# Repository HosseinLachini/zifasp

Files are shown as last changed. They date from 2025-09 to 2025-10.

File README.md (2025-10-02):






# SANA USBasp – Smart ZIF-Socket AVR Programmer

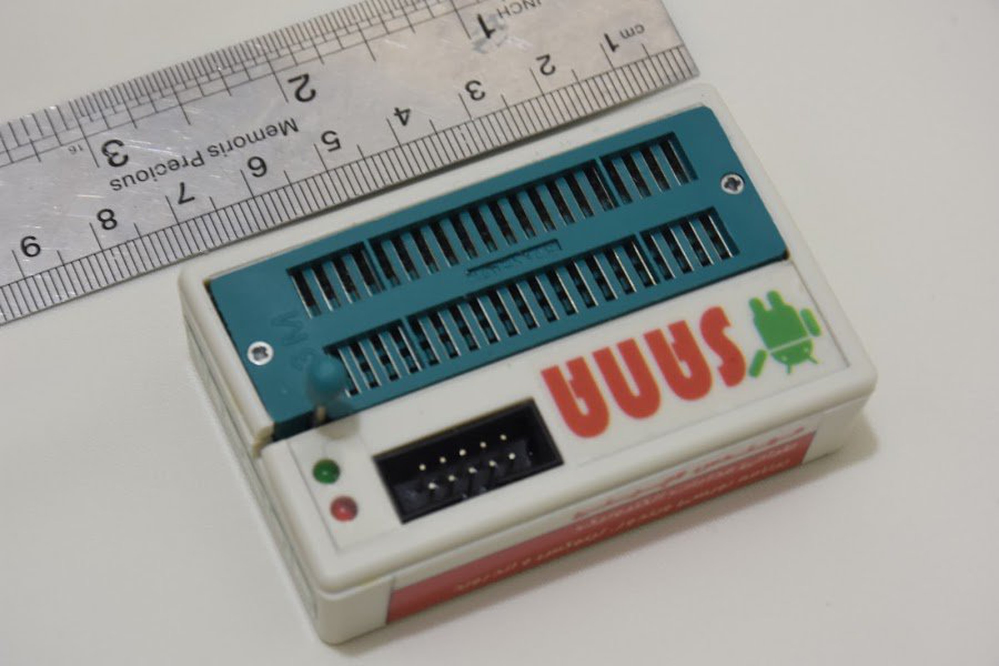
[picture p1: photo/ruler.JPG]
Pocket size — next to a ruler


A compact, USB-powered AVR programmer with an integrated **40-pin ZIF socket** and **auto-wiring** logic. It speaks the standard **USBasp** protocol, so it works out-of-the-box with `avrdude` on **Linux / Windows / macOS** — and even **Android** (OTG) via ZFlasher AVR.

> **Credit & Origin**  
> This project is **based on the original USBasp** by **Thomas Fischl** (the excellent reference design and idea). See: https://www.fischl.de/usbasp/  
> SANA USBasp extends that design with a smart ZIF socket, auto-detect wiring, on-board clock injection, status LEDs, **I²C/SPI EEPROM programming**, and more (details below).

---

## Highlights

- **Smart 40-pin ZIF socket** with **auto-detect package & wiring**  
  Drop any **DIP 8/14/20/28/40** AVR **starting at pin-1** in the ZIF — the programmer **detects the device position automatically** and routes all signals you need:
  `VCC`, `GND`, `RESET`, `SCK`, `MOSI`, `MISO`, and even an **external clock** to the MCU’s `XTAL1` pin when needed.  
  No jumpers, no DIP-switches, no relocating the chip for different packages.

- **Fuse-proof clock injection**  
  If fuses were set for an external clock/oscillator (and your chip “bricked” due to a disabled internal RC), SANA will **supply the clock** so you can program it again.

- **IDC-10 ISP header with clock out**  
  The 10-pin IDC connector also provides a **clock output** for in-circuit programming (**ISP**) on boards where the target oscillator isn’t running.

- **Driver-state indicator (Windows)**  
  Red LED stays on when the driver isn’t installed; once the USBasp driver is correctly installed, the **green LED** indicates proper enumeration.

- **I²C/SPI EEPROM programmer**  
  Supports popular serial EEPROM families: **24Cxxx** (I²C) and **93Cxx** (Microwire/SPI-like). You can read/write/verify these EEPROMs directly in the ZIF socket.  
  On **Windows**, the **ProgISP** utility provides a convenient GUI for these memories.

- **Pocket-size** — basically the footprint of a 40-pin ZIF; truly **grab-and-go**.

- **USB-powered** (5 V from the host).

- **Fully USBasp-compatible**  
  Works with `avrdude` and common GUI front-ends across Linux/Windows/macOS — plus **Android** via **ZFlasher AVR**.

- **Field-proven**  
  Used by customers in the **USA**, **Italy**, and **Netherlands**.

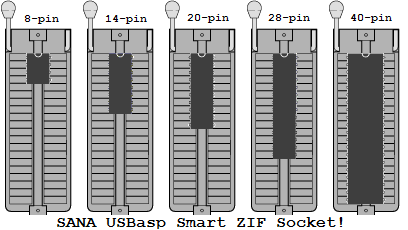
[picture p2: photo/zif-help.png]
ZIF placement guide — always start at pin-1


### IDC-10 ISP Header Pinout (SANA)

When programming targets in-circuit, use the **10-pin IDC** header. It also carries the **rescue clock** (`PROG_XTL1`) to keep “fuse-bricked” MCUs alive during programming.

> ⚠️ **Cautions**  
> • If your target board is self-powered, **do not connect PROG_VCC** (Pin 4).  
> • Always verify **keying/orientation** (Pin-1) before plugging the cable.  
> • For EEPROMs, ensure the device capacity matches the operation and that any **WP** (write-protect) pins are not asserted.  
> • If your target isn’t 5 V tolerant, use proper **level shifting** and power arrangements.

| Pin | Signal | Notes |
|:---:|---|---|
| 1 | PROG_SCK | SPI clock |
| 2 | PROG_GND | Ground |
| 3 | PROG_MISO | MCU → Programmer |
| 4 | PROG_VCC | **Optional** target power (disconnect if self-powered) |
| 5 | PROG_XTL1 | **Clock injection** to target `XTAL1` |
| 6 | PROG_RESET  | Target reset |
| 7 | — | Not connected |
| 8 | — | Not connected |
| 9 | PROG_MOSI | Programmer → MCU |
| 10  | PROG_GND | Ground |

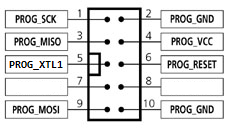
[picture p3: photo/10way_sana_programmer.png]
IDC-10 pinout — SANA programmer


---

## Repository Contents

- Firmware (ATmega88, V-USB/`usbdrv` based)
- Makefile with a friendly `help` target and robust tooling
- Source tree: `I2C/`, `Zif_Socket/`, `usbdrv/`, etc.
- Build artifacts are generated **outside** the source tree by default  
  → `../build/SANA_UsbAsp/…`

---

## Build From Source

### Prerequisites

- **Linux (Debian/Ubuntu):**
  ```bash
  sudo apt update
  sudo apt install -y build-essential gcc-avr avr-libc avrdude zip tar
  ```
- **macOS (Homebrew):**
  ```bash
  brew update
  brew tap osx-cross/avr
  brew install avr-gcc avrdude
  ```
- **Windows:**
  - Use **WSL** (Ubuntu) with the Linux commands above, or
  - Install an AVR toolchain (e.g., MSYS2/WinAVR) and `avrdude`.
  - Install the **USBasp driver** (e.g., via Zadig). The device’s **LEDs** will help: red → driver missing, green → OK.

### Get the code & build

```bash
git clone git@github.com:HosseinLachini/zifasp.git
cd zifasp/SANA_USBASP
# Show usage and current configuration
make

# Build everything (ELF, HEX, BIN, MAP + archives)
make all
```

**Outputs** (by default):  
`../build/SANA_UsbAsp/{SANA_UsbAsp.elf,.hex,.bin,.map,.zip,.tar.gz}`

> You can change the output root with `OUT_BASE`:
> ```bash
> make OUT_BASE=/abs/path/to/build all
> ```

### Helpful Make targets

```text
make               -> same as 'make help'
make help          -> show help & current variables
make all           -> build ELF/HEX/BIN (+ zip/tar.gz)
make main.hex      -> ensure HEX exists
make disasm        -> generate .lst from ELF
make clean         -> remove build directory
```

---

## Flashing the Firmware (to the ATmega88 on SANA)

With the device connected as a USBasp:

```bash
# Adjust -p if you change MCU; defaults target the ATmega88 (m88)
avrdude -c usbasp -p m88 -U flash:w:../build/SANA_UsbAsp/SANA_UsbAsp.hex:i
```

**Fuse caution:** only program fuses if you know what you’re doing. The Makefile provides helpers:

```bash
# Read fuses
make fuses-read

# Write fuses (example values)
make fuses-write LFUSE=0xEF HFUSE=0xC9   # (set values appropriate to your setup)
```

---

## Using the Programmer

1. **Standalone with ZIF socket (DIP packages)**  
   - Lift the lever, insert the AVR **starting at pin-1** (see figure), lower the lever.  
   - SANA auto-detects the package/position and internally routes `VCC/GND/RESET/SCK/MOSI/MISO`.  
   - If the target requires an **external clock** (due to fuses), SANA injects clock on `XTAL1`.

2. **In-System Programming (ISP) via IDC-10**  
   - Connect the **10-pin IDC** cable to the target.  
   - SANA also provides a **clock output** on the IDC header to revive targets with disabled oscillators.

3. **Serial EEPROMs (24Cxxx / 93Cxx)**  
   - Place the EEPROM in the ZIF starting at **pin‑1**.  
   - For **24Cxxx (I²C)** parts, SANA routes `SDA/SCL` and powers the device; for **93Cxx** parts, it routes `DO/DI/CLK/CS`.  
   - On **Windows**, you can use **ProgISP** for a simple GUI workflow to read/write/verify these EEPROMs. Other platforms can use command‑line tools or custom scripts.

4. **Host platforms**  
   - **Linux / macOS / Windows**: use `avrdude -c usbasp -p <part> ...` for AVR MCUs.  
   - **Android**: use **ZFlasher AVR** (Google Play):  
     https://play.google.com/store/apps/details?id=ru.zdevs.zflasheravr&hl=en

5. **LEDs (Windows driver hint)**  
   - **Red LED** steady: driver not installed.  
   - **Green LED**: device enumerated with correct driver.

> Power is drawn entirely from **USB**. If your target board isn’t 5 V-tolerant, use proper level shifting and power arrangements.

---

## Compatibility

- AVR DIP packages up to **40-pin** (e.g., ATmega8/88/168/328(P), ATmega16/32, many ATtiny devices, etc.).  
- Serial EEPROM families **24Cxxx** and **93Cxx** in DIP packages.  
- Fully compatible with the **USBasp** protocol (works wherever USBasp works).

---

## Screens & Size

- See **ruler photo** above for the overall external dimensions — the enclosure is only slightly larger than the 40-pin ZIF, making it truly pocketable.

---

## Support, Credits & Links

- **Original USBasp** by **Thomas Fischl** (primary idea & base design): https://www.fischl.de/usbasp/  
- **Project website (author):** https://www.elewiz.com/  
- **LinkedIn (author):** https://www.linkedin.com/in/hossein-lachini/

If you build or use this programmer, I’d love to hear from you — it’s already in the hands of users in the **USA**, **Italy**, and **Netherlands**.

---

## Troubleshooting

- `make`: prints usage if you forget a target; `make all` builds everything.  
- If `avrdude` can’t detect the device on Windows, install the USBasp driver; the **LEDs** indicate the state (red → missing driver, green → OK).  
- If a target MCU doesn’t respond due to fuse settings, try programming it in the **ZIF socket** (clock injection) or via ISP with the SANA clock output.  
- For EEPROMs, ensure the device capacity matches the operation and that WP pins (if any) are not asserted.

---

## License

This work builds upon and credits the original USBasp by Thomas Fischl.  
Please consult the repository for the exact firmware/license terms for SANA USBasp and any third-party components (e.g., V-USB/usbdrv).

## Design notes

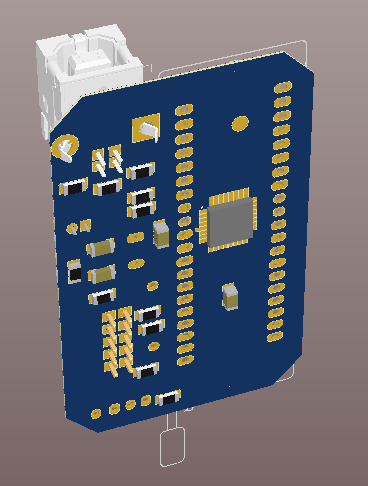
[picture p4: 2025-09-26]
schematic/BottomView.png

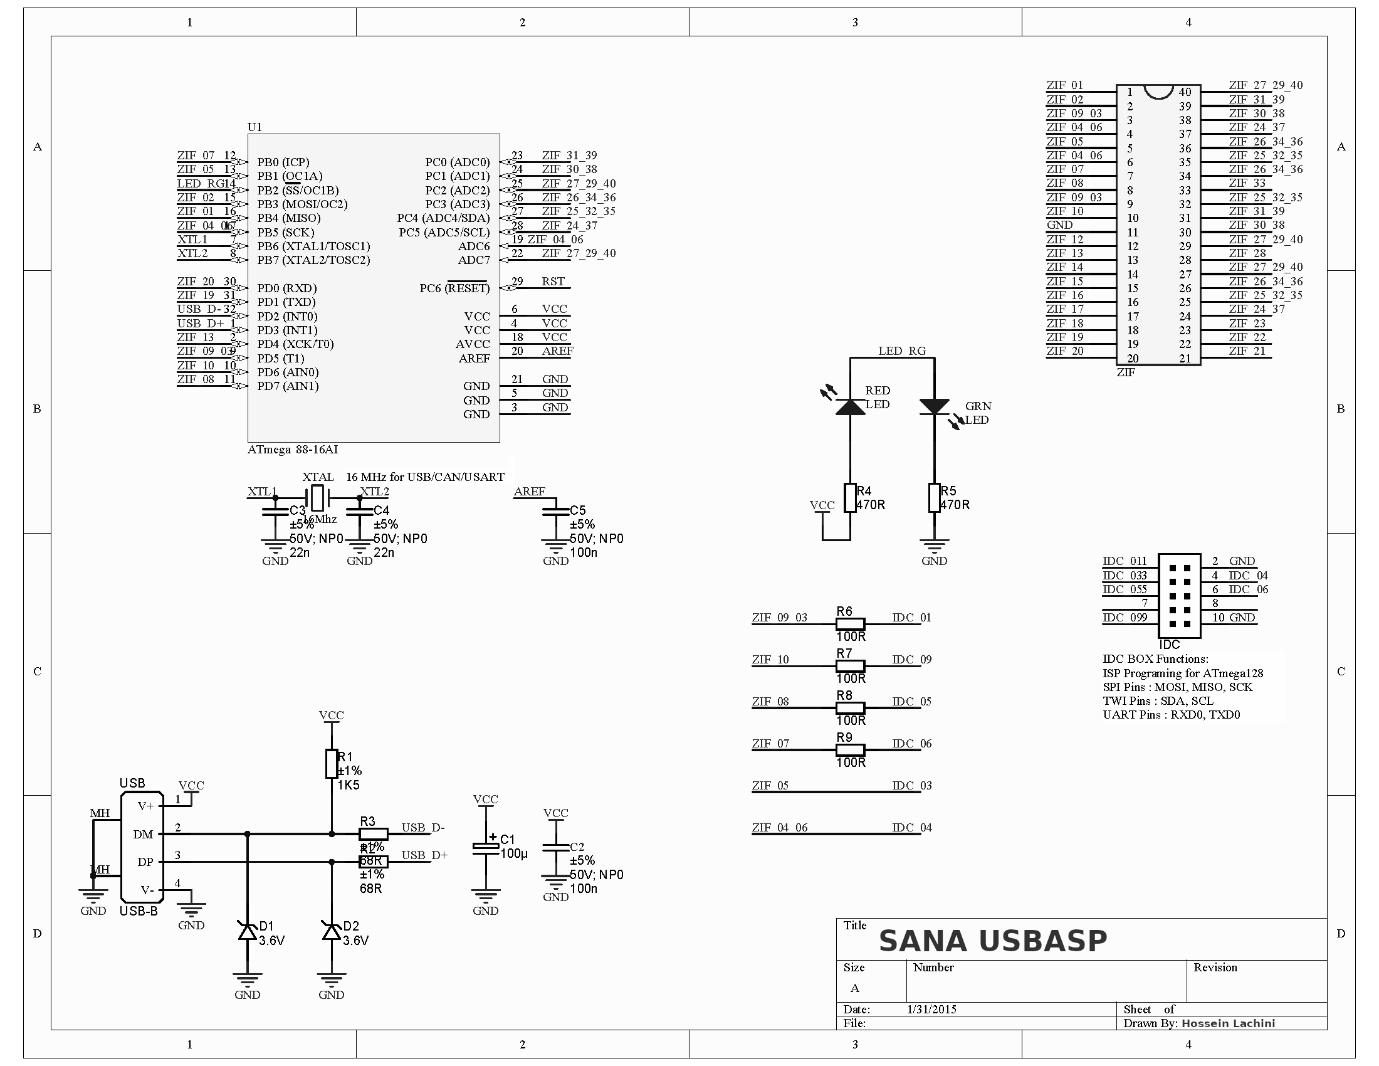
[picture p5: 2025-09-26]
schematic/Schematic.png

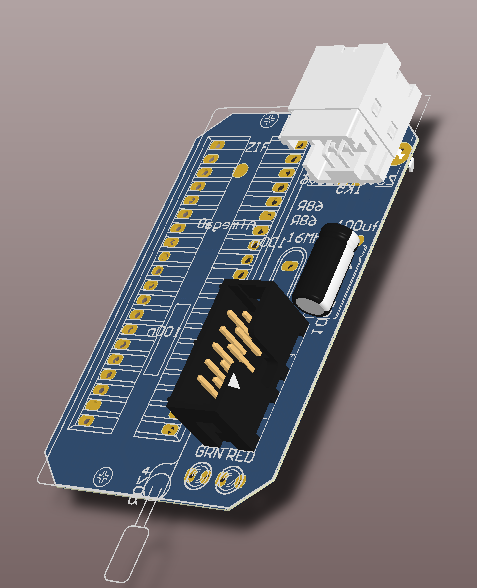
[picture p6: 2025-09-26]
schematic/TopView.png

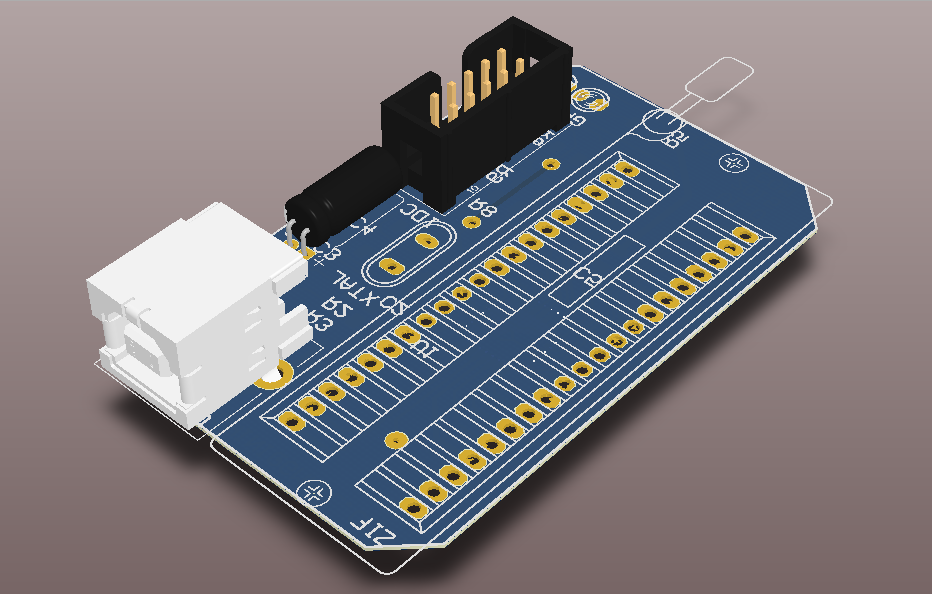
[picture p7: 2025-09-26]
schematic/SANA.png

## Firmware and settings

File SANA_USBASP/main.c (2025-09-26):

/*
 * USBasp - USB in-circuit programmer for Atmel AVR controllers
 *
 * Thomas Fischl <tfischl@gmx.de>
 *
 * License........: GNU GPL v2 (see Readme.txt)
 * Target.........: ATMega8 at 12 MHz
 * Creation Date..: 2005-02-20
 * Last change....: 2009-02-28
 *
 * PC2 SCK speed option.
 * GND  -> slow (8khz SCK),
 * open -> software set speed (default is 375kHz SCK)
 */

#include <avr/io.h>
#include <avr/interrupt.h>
#include <avr/pgmspace.h>
#include <avr/wdt.h>
#include <util/delay.h>

#include "usbasp.h"
#include "usbdrv/usbdrv.h"
#include "isp.h"
#include "clock.h"
#include "tpi.h"
#include "tpi_defs.h"
#include "Zif_Socket/zif.h"
#include "I2C/I2C.h"

/* compatibilty macros for old style */
#ifndef cbi
#define cbi(sfr, bit) (_SFR_BYTE(sfr) &= ~_BV(bit))
#endif

#ifndef sbi
#define sbi(sfr, bit) (_SFR_BYTE(sfr) |= _BV(bit))
#endif

static uchar replyBuffer[8];

static uchar prog_state = PROG_STATE_IDLE;
uchar prog_sck = USBASP_ISP_SCK_AUTO;

static uchar prog_address_newmode = 0;
static unsigned long prog_address;
static unsigned int prog_nbytes = 0;
static unsigned int prog_pagesize;
static uchar prog_blockflags;
static uchar prog_pagecounter;

static uchar i2cBackup[3];


uchar usbFunctionSetup(uchar data[8]) {

	uchar len = 0;

	//if (data[1] == USBASP_FUNC_BOOTLOADER)
    //    jump_to_boot();
	//if (data[1] == USBASP_FUNC_EXTENDED)
    //    return Extended(data);
	if (data[1] == USBASP_FUNC_CONNECT) {
        chip = data[3];
        switch(chip)
        {
        case PROGISP_24CXX:
            //i2cPins();
            i2cConnect();
            data[0] = 1;
            i2cSmart = 8;
            i2cReceive(0xa0, 0, 2, i2cBackup);
            i2cSmart = 16;
            i2cReceive(0xa0, 0, 1, i2cBackup + 2);
            i2cSend(0xa0, 0, 0, data);
            //chip = AT24CXX;
            /* set compatibility mode of address delivering */
            prog_address_newmode = 0;
            prog_address = 0;
            break;
        case PROGISP_93CXX:
            //chip = AT93CXX;
            //at93cxxConnect();
            break;
        case PROGISP_AVR:
        case PROGISP_MCS51:
            en_xtal = data[4] ? 0 : USBASP_EXT_RC_OSCILLATOR;
            //en_xtal = USBASP_EXT_OSCILLATOR;
            ispSetSCKOption(prog_sck);
            ispSearch();
            /* set SCK speed */
            //if ((PINE & (1 << PE0)) == 0) {
            //	ispSetSCKOption(USBASP_ISP_SCK_8);
            //} else {
            //}

            /* set compatibility mode of address delivering */
            prog_address_newmode = 0;

            ispConnect();
            break;
        }
        ledRedOn();
	} else if (data[1] == USBASP_FUNC_DISCONNECT) {
		//ispDisconnect();
		zif_disconnect();
		ledRedOff();

	} else if (data[1] == USBASP_FUNC_TRANSMIT) {
	    switch(chip) {
        case PROGISP_AVR :
            replyBuffer[0] = ispTransmit(data[2]);
            replyBuffer[1] = ispTransmit(data[3]);
            replyBuffer[2] = ispTransmit(data[4]);
            replyBuffer[3] = ispTransmit(data[5]);
            break;
	    case PROGISP_93CXX :
	        if(data[2] == 0xAC && data[3] == 0x80/* && data[4] == 0 && data[5] == 0*/) {
	        //if((unsigned long))
                //at93cxxErasesAll();
                replyBuffer[0] = '9';
                replyBuffer[1] = '3';
                replyBuffer[2] = 'E';
                replyBuffer[3] = 'A';
	        }
	        break;
        default :
            if(data[2]==0x24){
                replyBuffer[0] = ispTransmit(data[2]);
                replyBuffer[1] = ispTransmit(data[3]);
                replyBuffer[2] = ispTransmit(data[4]);
                switch(ispTransmit(data[5])&0x1C){
                    case(0x00):replyBuffer[3]=0xE0;break;
                    case(0x04):replyBuffer[3]=0xE5;break;
                    case(0x0C):replyBuffer[3]=0xEE;break;
                    case(0x1C):replyBuffer[3]=0xFF;break;
                    }
            }
            else if(data[2]==0x30){
                replyBuffer[0] = ispTransmit(0x28);
                replyBuffer[1] = ispTransmit(data[3]);
                replyBuffer[2] = ispTransmit(data[4]);
                replyBuffer[3] = ispTransmit(data[5]);
            }
            else{
                replyBuffer[0] = ispTransmit(data[2]);
                replyBuffer[1] = ispTransmit(data[3]);
                replyBuffer[2] = ispTransmit(data[4]);
                replyBuffer[3] = ispTransmit(data[5]);
            }
        }
		len = 4;

	} else if (data[1] == USBASP_FUNC_READFLASH) {

		if (!prog_address_newmode)
        {
            if(chip == PROGISP_24CXX)
            {
                prog_address = (data[3] << 8) | data[2];
            }
            else
            {
                prog_address = (data[3] << 8) | data[2];
            }
        }

		prog_nbytes = (data[7] << 8) | data[6];
		prog_state = PROG_STATE_READFLASH;
		len = 0xff; /* multiple in */

	} else if (data[1] == USBASP_FUNC_READEEPROM) {

		if (!prog_address_newmode)
			prog_address = (data[3] << 8) | data[2];

		prog_nbytes = (data[7] << 8) | data[6];
		prog_state = PROG_STATE_READEEPROM;
		len = 0xff; /* multiple in */

	} else if (data[1] == USBASP_FUNC_ENABLEPROG) {
	    switch(chip)
        {
        case PROGISP_24CXX :
            replyBuffer[0] = 0;
            i2cEnterProgrammingMode();
            switch(i2cSmart)
            {
            case 0:
                replyBuffer[0] = 1;
                break;
            case 8:
                i2cSend(0xa0, 0, 2, i2cBackup);
                break;
            case 16:
                i2cSend(0xa0, 0, 1, i2cBackup + 2);
                break;
            }
            break;
        case PROGISP_93CXX :
            //replyBuffer[0] = at93cxxEnterProgrammingMode();
            break;
        default :
            replyBuffer[0] = ispEnterProgrammingMode();
        }
		len = 1;

	} else if (data[1] == USBASP_FUNC_WRITEFLASH) {

		if (!prog_address_newmode)
			prog_address = (data[3] << 8) | data[2];

		prog_pagesize = data[4];
		prog_blockflags = data[5] & 0x0F;
		prog_pagesize += (((unsigned int) data[5] & 0xF0) << 4);
		if (prog_blockflags & PROG_BLOCKFLAG_FIRST) {
			prog_pagecounter = prog_pagesize;
		}
		prog_nbytes = (data[7] << 8) | data[6];
		prog_state = PROG_STATE_WRITEFLASH;
		len = 0xff; /* multiple out */

	} else if (data[1] == USBASP_FUNC_WRITEEEPROM) {

		if (!prog_address_newmode)
			prog_address = (data[3] << 8) | data[2];

		prog_pagesize = 0;
		prog_blockflags = 0;
		prog_nbytes = (data[7] << 8) | data[6];
		prog_state = PROG_STATE_WRITEEEPROM;
		len = 0xff; /* multiple out */

	} else if (data[1] == USBASP_FUNC_SETLONGADDRESS) {

		/* set new mode of address delivering (ignore address delivered in commands) */
		prog_address_newmode = 1;
		/* set new address */
		prog_address = *((unsigned long*) &data[2]);

	} else if (data[1] == USBASP_FUNC_SETISPSCK) {

		/* set sck option */
		prog_sck = data[2];
		replyBuffer[0] = 0;
		len = 1;

	} else if (data[1] == USBASP_FUNC_TPI_CONNECT) {
		tpi_dly_cnt = data[2] | (data[3] << 8);

		/* RST high */
		//ISP_OUT |= (1 << ISP_RST);
		//ISP_DDR |= (1 << ISP_RST);
		sbi(ISP_RST_PORT, ISP_RST);
		sbi(ISP_RST_DDR, ISP_RST);

		clockWait(3);

		/* RST low */
		//ISP_OUT &= ~(1 << ISP_RST);
		cbi(ISP_RST_PORT, ISP_RST);
		ledRedOn();

		clockWait(16);
		tpi_init();

	} else if (data[1] == USBASP_FUNC_TPI_DISCONNECT) {

		tpi_send_byte(TPI_OP_SSTCS(TPISR));
		tpi_send_byte(0);

		clockWait(10);

		/* pulse RST */
		//ISP_OUT |= (1 << ISP_RST);
		sbi(ISP_RST_PORT, ISP_RST);
		clockWait(5);
		//ISP_OUT &= ~(1 << ISP_RST);
		cbi(ISP_RST_PORT, ISP_RST);
		clockWait(5);

		/* set all ISP pins inputs */
		//ISP_DDR &= ~((1 << ISP_RST) | (1 << ISP_SCK) | (1 << ISP_MOSI));
		cbi(ISP_RST_DDR, ISP_RST);
        cbi(ISP_SCK_DDR, ISP_SCK);
        cbi(ISP_MOSI_DDR, ISP_MOSI);
		/* switch pullups off */
		//ISP_OUT &= ~((1 << ISP_RST) | (1 << ISP_SCK) | (1 << ISP_MOSI));

        cbi(ISP_RST_PORT, ISP_RST);
        cbi(ISP_SCK_PORT, ISP_SCK);
        cbi(ISP_MOSI_PORT, ISP_MOSI);

		ledRedOff();

	} else if (data[1] == USBASP_FUNC_TPI_RAWREAD) {
		replyBuffer[0] = tpi_recv_byte();
		len = 1;

	} else if (data[1] == USBASP_FUNC_TPI_RAWWRITE) {
		tpi_send_byte(data[2]);

	} else if (data[1] == USBASP_FUNC_TPI_READBLOCK) {
		prog_address = (data[3] << 8) | data[2];
		prog_nbytes = (data[7] << 8) | data[6];
		prog_state = PROG_STATE_TPI_READ;
		len = 0xff; /* multiple in */

	} else if (data[1] == USBASP_FUNC_TPI_WRITEBLOCK) {
		prog_address = (data[3] << 8) | data[2];
		prog_nbytes = (data[7] << 8) | data[6];
		prog_state = PROG_STATE_TPI_WRITE;
		len = 0xff; /* multiple out */

	} else if (data[1] == USBASP_FUNC_GETCAPABILITIES) {
		replyBuffer[0] = USBASP_CAP_0_TPI;
		replyBuffer[1] = 0;
		replyBuffer[2] = 0;
		replyBuffer[3] = 0;
		len = 4;
	}

	usbMsgPtr = replyBuffer;

	return len;
}

uchar usbFunctionRead(uchar *data, uchar len) {

	uchar i;

	/* check if programmer is in correct read state */
	if ((prog_state != PROG_STATE_READFLASH) && (prog_state
			!= PROG_STATE_READEEPROM) && (prog_state != PROG_STATE_TPI_READ)) {
		return 0xff;
	}

	/* fill packet TPI mode */
	if(prog_state == PROG_STATE_TPI_READ)
	{
		tpi_read_block(prog_address, data, len);
		prog_address += len;
		return len;
	}

	if(chip == PROGISP_24CXX)
    {
        if (prog_state == PROG_STATE_READFLASH)
        {
            i2cReceive(0xa0, prog_address, len, data);
            prog_address += len;
        }

        /* last packet? */
        if (len < 8) {
            prog_state = PROG_STATE_IDLE;
        }
        return len;
    }

	/* fill packet ISP mode */
	for (i = 0; i < len; i++) {
		if (prog_state == PROG_STATE_READFLASH) {
			data[i] = ispReadFlash(prog_address);
		} else {
			data[i] = ispReadEEPROM(prog_address);
		}
		prog_address++;
	}

	/* last packet? */
	if (len < 8) {
		prog_state = PROG_STATE_IDLE;
	}

	return len;
}

uchar usbFunctionWrite(uchar *data, uchar len) {

	uchar retVal = 0;
	uchar i;

	/* check if programmer is in correct write state */
	if ((prog_state != PROG_STATE_WRITEFLASH) && (prog_state
			!= PROG_STATE_WRITEEEPROM) && (prog_state != PROG_STATE_TPI_WRITE)) {
		return 0xff;
	}

	if(chip == PROGISP_24CXX)
    {
        if(prog_state == PROG_STATE_WRITEFLASH)
        {
            //while(prog_nbytes)
            {
                //if(i2cSmart)
                {
                    //for(i = 0; i < (len/i2cSmart); i+=i2cSmart)
                    //    i2cSend(0xa0, prog_address + i, i2cSmart, data + i);
                    //for(; i < len; i++)
                    //    i2cSend(0xa0, prog_address + i, 1, data + i);
                    //for(i = 0; i < len; i++)
                    //    i2cSend(0xa0, prog_address + i, 1, data + i);
                    i2cWriteBlock( data, len, prog_address);
                }
                //else
                //{
                //    for(i = 0; i < len; i+=8)
                //        i2cSendStandard(0xa0, prog_address + i, 8, data + i);
                //}
                prog_address += len;
                prog_nbytes -= len;
                if(prog_nbytes <= 0)
                {
                    prog_state = PROG_STATE_IDLE;
                    return 1;
                }
            }
            return 0;
        }
    }

	if (prog_state == PROG_STATE_TPI_WRITE)
	{
		tpi_write_block(prog_address, data, len);
		prog_address += len;
		prog_nbytes -= len;
		if(prog_nbytes <= 0)
		{
			prog_state = PROG_STATE_IDLE;
			return 1;
		}
		return 0;
	}

	for (i = 0; i < len; i++) {

		if (prog_state == PROG_STATE_WRITEFLASH) {
			/* Flash */

			if (prog_pagesize == 0) {
				/* not paged */
				ispWriteFlash(prog_address, data[i], 1);
			} else {
				/* paged */
				ispWriteFlash(prog_address, data[i], 0);
				prog_pagecounter--;
				if (prog_pagecounter == 0) {
					ispFlushPage(prog_address, data[i]);
					prog_pagecounter = prog_pagesize;
				}
			}

		} else {
			/* EEPROM */
			ispWriteEEPROM(prog_address, data[i]);
		}

		prog_nbytes--;

		if (prog_nbytes == 0) {
			prog_state = PROG_STATE_IDLE;
			if ((prog_blockflags & PROG_BLOCKFLAG_LAST) && (prog_pagecounter
					!= prog_pagesize)) {

				/* last block and page flush pending, so flush it now */
				ispFlushPage(prog_address, data[i]);
			}

			retVal = 1; // Need to return 1 when no more data is to be received
		}

		prog_address++;
	}

	return retVal;
}

static void initForUsbConnectivity(void)
{
    uchar   i = 0;
    usbInit();
    /* enforce USB re-enumerate: */
    usbDeviceDisconnect();  /* do this while interrupts are disabled */
    do{             /* fake USB disconnect for > 250 ms */
        wdt_reset();
        _delay_ms(1);
    }while(--i);
    usbDeviceConnect();
    sei();
}

int main(void) {
/*
    unsigned char d = 0x01;
    //i2cPins();
    _delay_ms(2000);
    i2cConnect();
    i2cSmart = 16;
    i2cSend(0xa0, 0, 1, &d);
	ledRedInit();
	ledGreenOn();
    i2cEnterProgrammingMode();
    while(1);
*/
	ledRedInit();
	//ledGreenInit();
	ledRedOn();
	//ledGreenOn();
	initForUsbConnectivity();

    chip = PROGISP_AVR;

	/* init timer */
	clockInit();

	/* main event loop */
	for (;;) {
		usbPoll();
	}
	return 0;
}

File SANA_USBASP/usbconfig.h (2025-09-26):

/* Name: usbconfig.h
 * Project: AVR USB driver
 * Author: Christian Starkjohann, Thomas Fischl
 * Creation Date: 2005-04-01
 * Tabsize: 4
 * Copyright: (c) 2005 by OBJECTIVE DEVELOPMENT Software GmbH
 * License: GNU GPL v2 (see License.txt) or proprietary (CommercialLicense.txt)
 */

#ifndef __usbconfig_h_included__
#define __usbconfig_h_included__

/*
General Description:
This file contains parts of the USB driver which can be configured and can or
must be adapted to your hardware.

Please note that the usbdrv contains a usbconfig-prototype.h file now. We
recommend that you use that file as a template because it will always list
the newest features and options.
*/

/* ---------------------------- Hardware Config ---------------------------- */

#define USB_CFG_IOPORTNAME      D
/* This is the port where the USB bus is connected. When you configure it to
 * "B", the registers PORTB, PINB and DDRB will be used.
 */
#define USB_CFG_DMINUS_BIT      3
/* This is the bit number in USB_CFG_IOPORT where the USB D- line is connected.
 * This may be any bit in the port.
 */
#define USB_CFG_DPLUS_BIT       2
/* This is the bit number in USB_CFG_IOPORT where the USB D+ line is connected.
 * This may be any bit in the port. Please note that D+ must also be connected
 * to interrupt pin INT0!
 */
#define USB_CFG_CLOCK_KHZ 16000
/* Clock rate of the AVR in MHz. Legal values are 12000, 16000 or 16500.
 * The 16.5 MHz version of the code requires no crystal, it tolerates +/- 1%
 * deviation from the nominal frequency. All other rates require a precision
 * of 2000 ppm and thus a crystal!
 * Default if not specified: 12 MHz
 */

/* ----------------------- Optional Hardware Config ------------------------ */

/* #define USB_CFG_PULLUP_IOPORTNAME   D */
/* If you connect the 1.5k pullup resistor from D- to a port pin instead of
 * V+, you can connect and disconnect the device from firmware by calling
 * the macros usbDeviceConnect() and usbDeviceDisconnect() (see usbdrv.h).
 * This constant defines the port on which the pullup resistor is connected.
 */
/* #define USB_CFG_PULLUP_BIT          4 */
/* This constant defines the bit number in USB_CFG_PULLUP_IOPORT (defined
 * above) where the 1.5k pullup resistor is connected. See description
 * above for details.
 */

/* --------------------------- Functional Range ---------------------------- */

#define USB_CFG_HAVE_INTRIN_ENDPOINT    0
/* Define this to 1 if you want to compile a version with two endpoints: The
 * default control endpoint 0 and an interrupt-in endpoint 1.
 */
#define USB_CFG_HAVE_INTRIN_ENDPOINT3   0
/* Define this to 1 if you want to compile a version with three endpoints: The
 * default control endpoint 0, an interrupt-in endpoint 1 and an interrupt-in
 * endpoint 3. You must also enable endpoint 1 above.
 */
#define USB_CFG_IMPLEMENT_HALT          0
/* Define this to 1 if you also want to implement the ENDPOINT_HALT feature
 * for endpoint 1 (interrupt endpoint). Although you may not need this feature,
 * it is required by the standard. We have made it a config option because it
 * bloats the code considerably.
 */
#define USB_CFG_INTR_POLL_INTERVAL      10
/* If you compile a version with endpoint 1 (interrupt-in), this is the poll
 * interval. The value is in milliseconds and must not be less than 10 ms for
 * low speed devices.
 */
#define USB_CFG_IS_SELF_POWERED         0
/* Define this to 1 if the device has its own power supply. Set it to 0 if the
 * device is powered from the USB bus.
 */
#define USB_CFG_MAX_BUS_POWER           50
/* Set this variable to the maximum USB bus power consumption of your device.
 * The value is in milliamperes. [It will be divided by two since USB
 * communicates power requirements in units of 2 mA.]
 */
#define USB_CFG_IMPLEMENT_FN_WRITE      1
/* Set this to 1 if you want usbFunctionWrite() to be called for control-out
 * transfers. Set it to 0 if you don't need it and want to save a couple of
 * bytes.
 */
#define USB_CFG_IMPLEMENT_FN_READ       1
/* Set this to 1 if you need to send control replies which are generated
 * "on the fly" when usbFunctionRead() is called. If you only want to send
 * data from a static buffer, set it to 0 and return the data from
 * usbFunctionSetup(). This saves a couple of bytes.
 */
#define USB_CFG_IMPLEMENT_FN_WRITEOUT   0
/* Define this to 1 if you want to use interrupt-out (or bulk out) endpoint 1.
 * You must implement the function usbFunctionWriteOut() which receives all
 * interrupt/bulk data sent to endpoint 1.
 */
#define USB_CFG_HAVE_FLOWCONTROL        0
/* Define this to 1 if you want flowcontrol over USB data. See the definition
 * of the macros usbDisableAllRequests() and usbEnableAllRequests() in
 * usbdrv.h.
 */

/* -------------------------- Device Description --------------------------- */
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

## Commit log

2025-09-26 Initial commit with Git LFS for Altium binaries
    [SanaUSBasp.PcbDoc, SanaUSBasp.SchDoc]
2025-09-26 docs(readme): add IDC-10 ISP pinout (table) and image; add cautions
    - Document 10-pin IDC connector signals, including PROG_XTL1 clock injection
    - Add safety notes: optional PROG_VCC, orientation (Pin-1), EEPROM WP, 5V level shifting
    - Embed pinout image at photo/10way_sana_programmer.png

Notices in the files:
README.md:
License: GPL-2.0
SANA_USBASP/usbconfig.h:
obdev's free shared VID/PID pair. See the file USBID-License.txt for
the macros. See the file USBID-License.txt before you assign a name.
